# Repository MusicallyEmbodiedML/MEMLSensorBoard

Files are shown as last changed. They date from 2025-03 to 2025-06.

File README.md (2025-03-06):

# MEMLSensorBoard

Host board for up to 8 resistive sensors, with adjustable scale and offset.  Send to another board using serial or i2c.  Visual feedback with TFT screen.

## Hardware

Also hosts a ELI2040c board https://github.com/Emute-Lab-Instruments/ELI2040

## Software 

Runs on RP2040

Need TFT eSPI extension, with RP2040 GC9A01 driver

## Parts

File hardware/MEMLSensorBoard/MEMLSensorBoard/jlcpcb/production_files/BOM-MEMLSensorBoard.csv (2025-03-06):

Comment | Designator | Footprint | LCSC
100n | C1,C13,C14,C15,C16,C17,C18,C19,C2,C20,C3 | C_0603_1608Metric | C14663
1N5819 | D1 | D_SOD-323 | C191023
taper 0R0 | R25,R26,R27,R28,R29,R30,R31,R32 | R_0603_1608Metric | C21189
2k | R10,R12,R14,R16,R2,R4,R6,R8 | R_0603_1608Metric | C22975
22uf | C4 | C_0805_2012Metric | C45783
MCP6004 | U2,U3 | TSSOP-14_4.4x5mm_P0.65mm | C50282
100p | C10,C11,C12,C5,C6,C7,C8,C9 | C_Rect_L7.0mm_W2.5mm_P5.00mm | C5359302
74HC4051 | U4 | TSSOP-16_4.4x5mm_P0.65mm | C5645
Screw_Terminal_01x02 | J2,J3,J4,J5,J6,J7,J8,J9 | CONN-TH_WJ126V-5.0-2P | C8404
100k | RV11 | TRIM_3306F-1-104
100k | RV5 | TRIM_3306F-1-104
5k DNP | R3 | R_Axial_DIN0207_L6.3mm_D2.5mm_P7.62mm_Horizontal
~ | U1 | Round TFT 240x240
100k | RV13 | TRIM_3306F-1-104
taper-dnp | R18 | R_0603_1608Metric
taper-dnp | R24 | R_0603_1608Metric
5k DNP | R7 | R_Axial_DIN0207_L6.3mm_D2.5mm_P7.62mm_Horizontal
100k | RV1 | TRIM_3306F-1-104
100k | RV12 | TRIM_3306F-1-104
ELI2040B 1 | J1 | PinSocket_1x35_P2.54mm_Vertical
100k | RV8 | TRIM_3306F-1-104
5k DNP | R13 | R_Axial_DIN0207_L6.3mm_D2.5mm_P7.62mm_Horizontal
taper-dnp | R19 | R_0603_1608Metric
5k DNP | R9 | R_Axial_DIN0207_L6.3mm_D2.5mm_P7.62mm_Horizontal
Conn_02x03_Counter_Clockwise | J10 | IDC-Header_2x04_P2.54mm_Vertical
100k | RV9 | TRIM_3306F-1-104
100k | RV7 | TRIM_3306F-1-104
100k | RV3 | TRIM_3306F-1-104
100k | RV6 | TRIM_3306F-1-104
5k DNP | R1 | R_Axial_DIN0207_L6.3mm_D2.5mm_P7.62mm_Horizontal
100k | RV10 | TRIM_3306F-1-104
100k | RV4 | TRIM_3306F-1-104
100k | RV16 | TRIM_3306F-1-104
taper-dnp | R20 | R_0603_1608Metric
100k | RV14 | TRIM_3306F-1-104
5k DNP | R11 | R_Axial_DIN0207_L6.3mm_D2.5mm_P7.62mm_Horizontal
Conn_01x04 | J12 | PinHeader_1x04_P2.54mm_Vertical
100k | RV15 | TRIM_3306F-1-104
taper-dnp | R21 | R_0603_1608Metric
5k DNP | R15 | R_Axial_DIN0207_L6.3mm_D2.5mm_P7.62mm_Horizontal
Conn_02x16_Counter_Clockwise | J11 | IDC-Header_2x08_P2.54mm_Vertical
5k DNP | R5 | R_Axial_DIN0207_L6.3mm_D2.5mm_P7.62mm_Horizontal
taper-dnp | R22 | R_0603_1608Metric
100k | RV2 | TRIM_3306F-1-104
taper-dnp | R17 | R_0603_1608Metric
taper-dnp | R23 | R_0603_1608Metric

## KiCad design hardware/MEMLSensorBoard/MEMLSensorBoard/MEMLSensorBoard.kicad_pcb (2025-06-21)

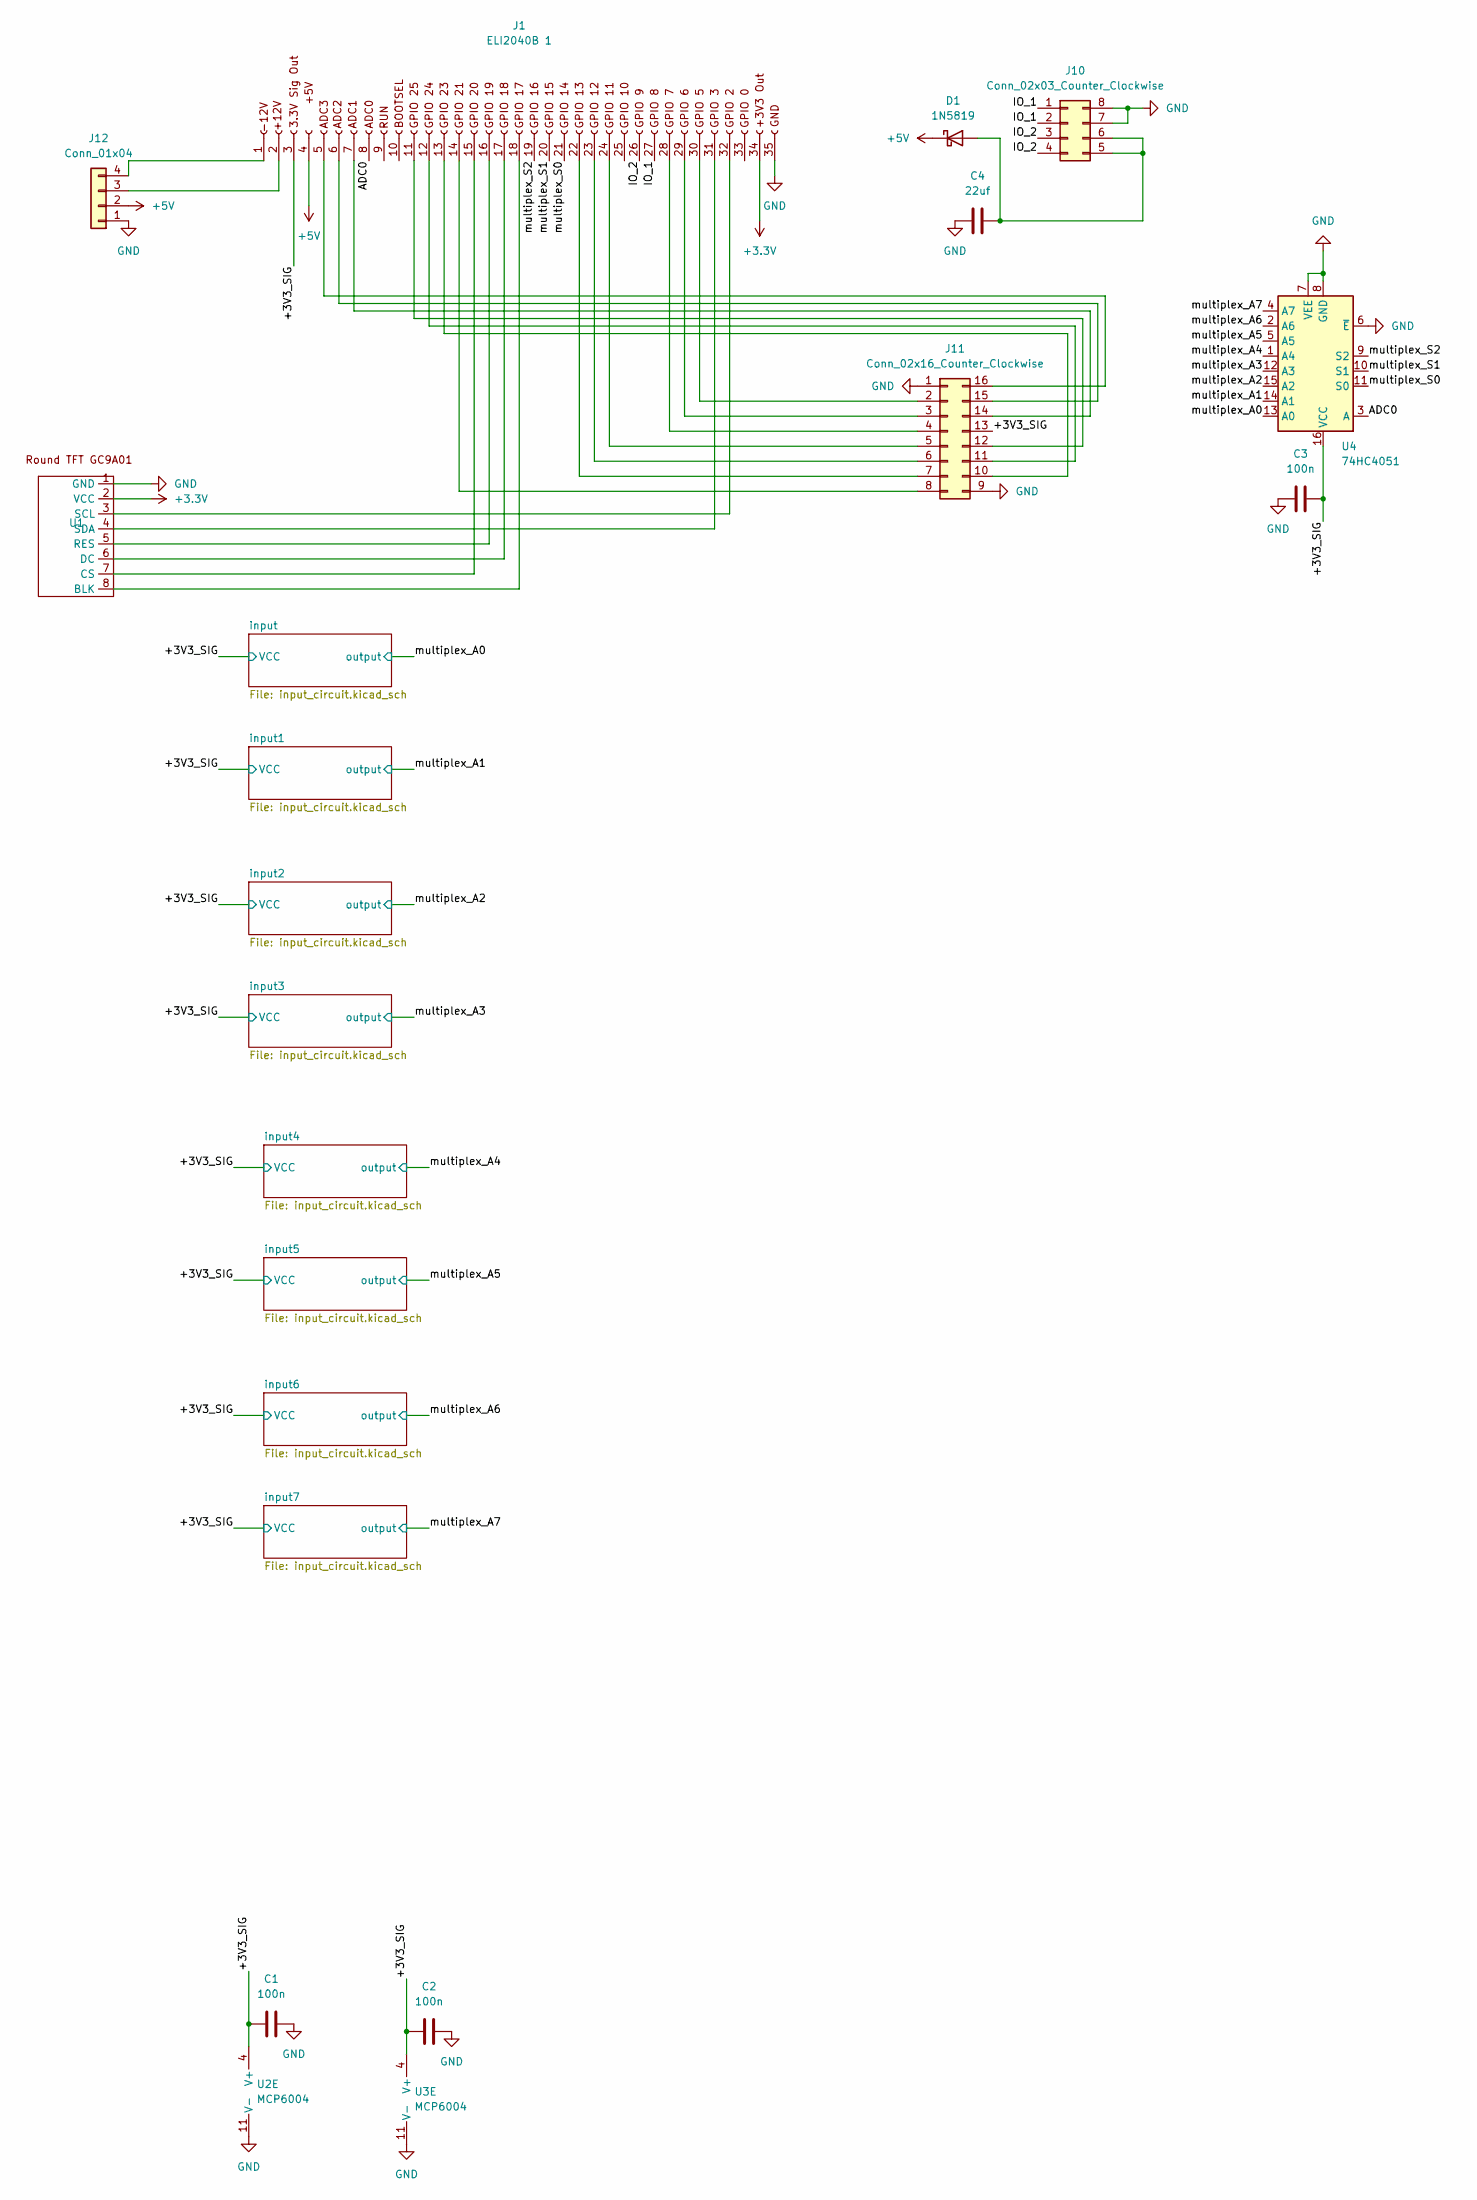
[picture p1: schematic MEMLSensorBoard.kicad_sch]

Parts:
C1, C2, C3: 100n; C_0603_1608Metric
C4: 22uf; C_0805_2012Metric
D1: 1N5819; D_SOD-323
J1: ELI2040B 1; PinSocket_1x35_P2.54mm_Vertical
J10: Conn_02x03_Counter_Clockwise; IDC-Header_2x04_P2.54mm_Vertical
J11: Conn_02x16_Counter_Clockwise; IDC-Header_2x08_P2.54mm_Vertical
J12: Conn_01x04; PinHeader_1x04_P2.54mm_Vertical
U1: Round TFT 240x240
U2, U3: MCP6004; TSSOP-14_4.4x5mm_P0.65mm
U4: 74HC4051; TSSOP-16_4.4x5mm_P0.65mm

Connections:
+3.3V: J1.34, U1.2 (VCC)
+5V: D1.1 (K), J1.4, J12.2
/+3V3_SIG: C1.1, C2.1, C3.1, J1.3, J11.13, U2.4 (V+), U3.4 (V+), U4.16 (VCC); also elsewhere on the board
/ADC0: J1.8, U4.3 (A)
/IO_1: J1.27, J10.1, J10.2
/IO_2: J1.26, J10.3, J10.4
/multiplex_A0: U2.1, U4.13 (A0); also elsewhere on the board
/multiplex_A1: U2.7, U4.14 (A1); also elsewhere on the board
/multiplex_A2: U4.15 (A2); also elsewhere on the board
/multiplex_A3: U2.14, U4.12 (A3); also elsewhere on the board
/multiplex_A4: U3.1, U4.1 (A4); also elsewhere on the board
/multiplex_A5: U3.7, U4.5 (A5); also elsewhere on the board
/multiplex_A6: U4.2 (A6); also elsewhere on the board
/multiplex_A7: U3.14, U4.4 (A7); also elsewhere on the board
/multiplex_S0: J1.21, U4.11 (S0)
/multiplex_S1: J1.20, U4.10 (S1)
/multiplex_S2: J1.19, U4.9 (S2)
GND: C1.2, C2.2, C3.2, C4.1, J1.35, J10.7, J10.8, J11.1, J11.9, J12.1, U1.1 (GND), U2.11 (V-), U3.11 (V-), U4.6 (~E), U4.7 (VEE), U4.8 (GND); also elsewhere on the board
unnamed: C4.2, D1.2 (A), J10.5, J10.6
unnamed: J1.2 (+12V), J12.3
unnamed: J1.1 (-12V), J12.4
unnamed: J1.5, J11.16
unnamed: J1.6, J11.15
unnamed: J1.7, J11.14
unnamed: J1.11, J11.12
unnamed: J1.12, J11.11
unnamed: J1.13, J11.10
unnamed: J1.14, J11.8
unnamed: J1.15, U1.7 (CS)
unnamed: J1.16, U1.5 (RES)
unnamed: J1.17, U1.6 (DC)
unnamed: J1.18, U1.8 (BLK)
unnamed: J1.22, J11.7
unnamed: J1.23, J11.6
unnamed: J1.24, J11.5
unnamed: J1.28, J11.4
unnamed: J1.29, J11.3
unnamed: J1.30, J11.2
unnamed: J1.31, U1.4 (SDA)
unnamed: J1.32, U1.3 (SCL)
unnamed 56: U2.3 (+); also elsewhere on the board
unnamed 57: U2.2 (-); also elsewhere on the board
unnamed 58: U2.5 (+); also elsewhere on the board
unnamed 59: U2.6 (-); also elsewhere on the board
unnamed 62: U2.12 (+); also elsewhere on the board
unnamed 63: U2.13 (-); also elsewhere on the board
unnamed 64: U3.3 (+); also elsewhere on the board
unnamed 65: U3.2 (-); also elsewhere on the board
unnamed 66: U3.5 (+); also elsewhere on the board
unnamed 67: U3.6 (-); also elsewhere on the board
unnamed 70: U3.12 (+); also elsewhere on the board
unnamed 71: U3.13 (-); also elsewhere on the board

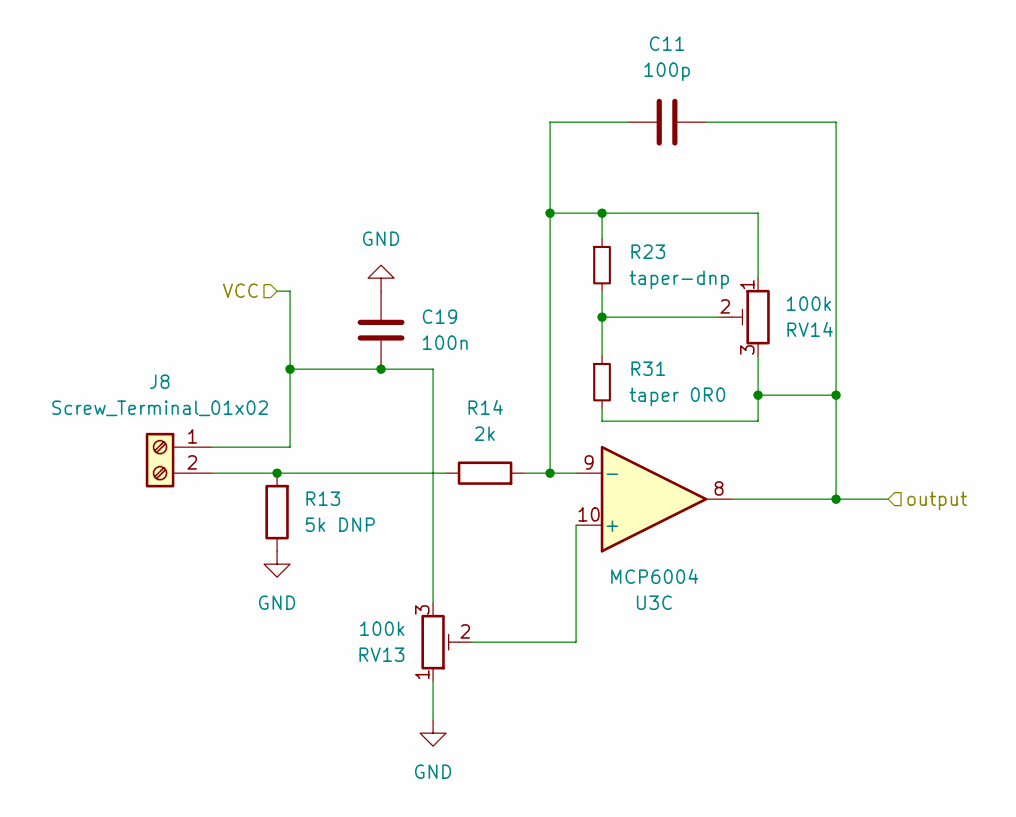
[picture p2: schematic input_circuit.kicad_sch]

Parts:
C11: 100p; C_Rect_L7.0mm_W2.5mm_P5.00mm; JLC C5359302
C19: 100n; C_0603_1608Metric
J8: Screw_Terminal_01x02; CONN-TH_WJ126V-5.0-2P; part WJ126V-5.0-2P; jlc C8404
R13: 5k DNP; R_Axial_DIN0207_L6.3mm_D2.5mm_P7.62mm_Horizontal
R14: 2k; R_0603_1608Metric
R23: taper-dnp; R_0603_1608Metric
R31: taper 0R0; R_0603_1608Metric; JLC C21189
RV13, RV14: 100k; TRIM_3306F-1-104
U3: MCP6004; TSSOP-14_4.4x5mm_P0.65mm

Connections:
/+3V3_SIG: C19.2, J8.1, RV13.3; also elsewhere on the board
/multiplex_A4: U3.1; also elsewhere on the board
/multiplex_A5: U3.7; also elsewhere on the board
/multiplex_A6: C11.2, R31.2, RV14.3, U3.8; also elsewhere on the board
/multiplex_A7: U3.14; also elsewhere on the board
GND: C19.1, R13.1, RV13.1; also elsewhere on the board
unnamed: J8.2, R13.2, R14.1
unnamed: R23.2, R31.1, RV14.2
unnamed 64: U3.3 (+); also elsewhere on the board
unnamed 65: U3.2 (-); also elsewhere on the board
unnamed 66: U3.5 (+); also elsewhere on the board
unnamed 67: U3.6 (-); also elsewhere on the board
unnamed: RV13.2, U3.10 (+)
unnamed: C11.1, R14.2, R23.1, RV14.1, U3.9 (-)
unnamed 70: U3.12 (+); also elsewhere on the board
unnamed 71: U3.13 (-); also elsewhere on the board

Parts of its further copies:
C5, C6, C7, C8, C9, C10, C12: 100p; C_Rect_L7.0mm_W2.5mm_P5.00mm; JLC C5359302
C13, C14, C15, C16, C17, C18, C20: 100n; C_0603_1608Metric
J2, J3, J4, J5, J6, J7, J9: Screw_Terminal_01x02; CONN-TH_WJ126V-5.0-2P; part WJ126V-5.0-2P; jlc C8404
R1, R3, R5, R7, R9, R11, R15: 5k DNP; R_Axial_DIN0207_L6.3mm_D2.5mm_P7.62mm_Horizontal
R2, R4, R6, R8, R10, R12, R16: 2k; R_0603_1608Metric
R17, R18, R19, R20, R21, R22, R24: taper-dnp; R_0603_1608Metric
R25, R26, R27, R28, R29, R30, R32: taper 0R0; R_0603_1608Metric; JLC C21189
RV1, RV2, RV3, RV4, RV5, RV6, RV7, RV8, RV9, RV10, RV11, RV12, RV15, RV16: 100k; TRIM_3306F-1-104

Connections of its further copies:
/+3V3_SIG: C13.2, C14.2, C15.2, C16.2, C17.2, C18.2, C20.2, J2.1, J3.1, J4.1, J5.1, J6.1, J7.1, J9.1, RV1.3, RV3.3, RV5.3, RV7.3, RV9.3, RV11.3, RV15.3; also elsewhere on the board
/multiplex_A0: C5.2, R25.2, RV2.3; also elsewhere on the board
/multiplex_A1: C6.2, R26.2, RV4.3; also elsewhere on the board
/multiplex_A2: C7.2, R27.2, RV6.3; also elsewhere on the board
/multiplex_A3: C8.2, R28.2, RV8.3; also elsewhere on the board
/multiplex_A4: C9.2, R29.2, RV10.3; also elsewhere on the board
/multiplex_A5: C10.2, R30.2, RV12.3; also elsewhere on the board
/multiplex_A7: C12.2, R32.2, RV16.3; also elsewhere on the board
GND: C13.1, C14.1, C15.1, C16.1, C17.1, C18.1, C20.1, R1.1, R3.1, R5.1, R7.1, R9.1, R11.1, R15.1, RV1.1, RV3.1, RV5.1, RV7.1, RV9.1, RV11.1, RV15.1; also elsewhere on the board
unnamed: J2.2, R1.2, R2.1
unnamed: J3.2, R3.2, R4.1
unnamed: J4.2, R5.2, R6.1
unnamed: J5.2, R7.2, R8.1
unnamed: J6.2, R9.2, R10.1
unnamed: J7.2, R11.2, R12.1
unnamed: J9.2, R15.2, R16.1
unnamed: R17.2, R25.1, RV2.2
unnamed: R18.2, R26.1, RV4.2
unnamed: R19.2, R27.1, RV6.2
unnamed: R20.2, R28.1, RV8.2
unnamed: R21.2, R29.1, RV10.2
unnamed: R22.2, R30.1, RV12.2
unnamed: R24.2, R32.1, RV16.2
unnamed 56: RV1.2; also elsewhere on the board
unnamed 57: C5.1, R2.2, R17.1, RV2.1; also elsewhere on the board
unnamed 58: RV3.2; also elsewhere on the board
unnamed 59: C6.1, R4.2, R18.1, RV4.1; also elsewhere on the board
unnamed 60: RV5.2; also elsewhere on the board
unnamed 61: C7.1, R6.2, R19.1, RV6.1; also elsewhere on the board
unnamed 62: RV7.2; also elsewhere on the board
unnamed 63: C8.1, R8.2, R20.1, RV8.1; also elsewhere on the board
unnamed 64: RV9.2; also elsewhere on the board
unnamed 65: C9.1, R10.2, R21.1, RV10.1; also elsewhere on the board
unnamed 66: RV11.2; also elsewhere on the board
unnamed 67: C10.1, R12.2, R22.1, RV12.1; also elsewhere on the board
unnamed 70: RV15.2; also elsewhere on the board
unnamed 71: C12.1, R16.2, R24.1, RV16.1; also elsewhere on the board

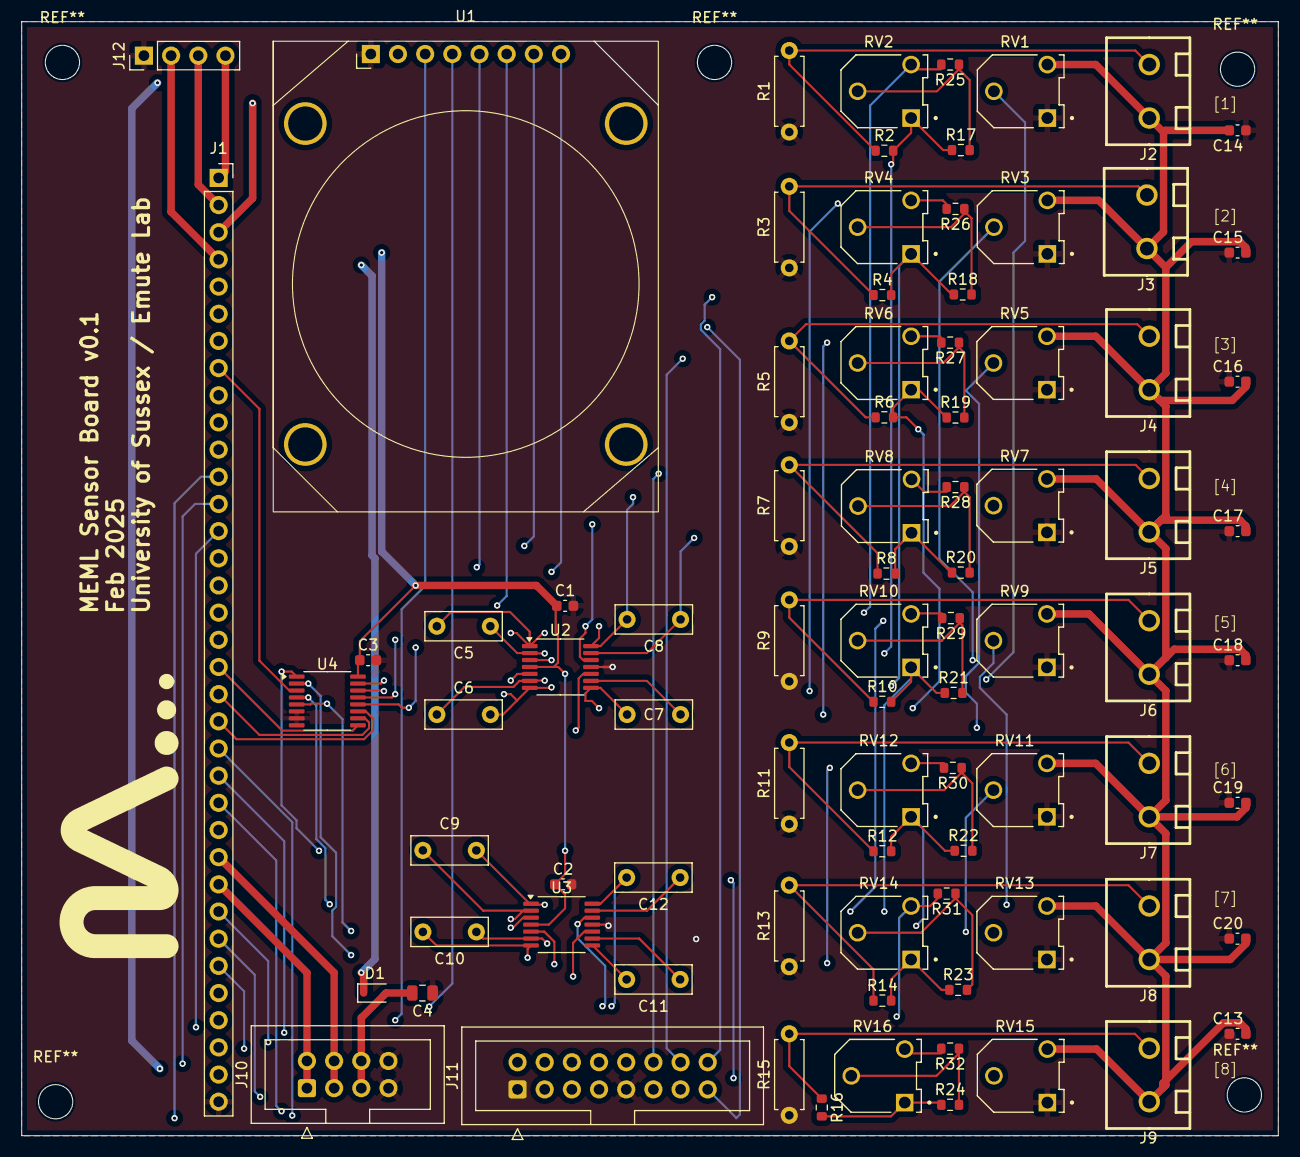
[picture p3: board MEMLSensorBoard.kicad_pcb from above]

Board: 4 copper layers, 117.5 x 104.1 mm, 85 parts (0 on the bottom side), 72 nets.

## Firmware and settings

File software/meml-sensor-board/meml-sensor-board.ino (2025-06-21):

#include <TFT_eSPI.h>
#include <array>
#include "pico/util/queue.h"
#include "SerialComms.hpp"

#define FAST_MEM __not_in_flash("data")

constexpr size_t MULTIPLEX_S0 = 14;
constexpr size_t MULTIPLEX_S1 = 15;
constexpr size_t MULTIPLEX_S2 = 16;


TFT_eSPI tft = TFT_eSPI();  // Invoke custom library
struct repeating_timer timerDisplay;

//sensors
std::array<size_t, 8> FAST_MEM sensorReadings, sensorReadingsCore1;
static queue_t FAST_MEM q_sensors;


inline bool __not_in_flash_func(displayUpdate)(__unused struct repeating_timer *t) {
  constexpr int barwidth = 16;
  constexpr int barheight=135;
  constexpr int barbase= 120 - (barheight/2.0);
  constexpr int barGap=18;
  constexpr int barcol = TFT_RED;
  constexpr int barcol2 = TFT_BLUE;
  constexpr int barLeft = 120 - (barGap*4);
  if (queue_try_remove(&q_sensors, sensorReadingsCore1.data())) {
    for(size_t i=0; i < 8; i++) {
      int thisBarHeight = barheight * (sensorReadingsCore1[i] / 4096.0);
      thisBarHeight = max(5, thisBarHeight);
      thisBarHeight = min(barheight, thisBarHeight);
      Serial.printf("%d %d %d\n", i, thisBarHeight, barheight - thisBarHeight);
      tft.fillRect(barLeft + (i * barGap), barbase, barwidth, barbase + thisBarHeight, barcol);
      tft.fillRect(barLeft + (i * barGap), barbase + thisBarHeight, barwidth, barheight - thisBarHeight, barcol2);
    }
  }
  return true;
}


void setup() {
  // put your setup code here, to run once:
  pinMode(22,1);
  pinMode(MULTIPLEX_S0, 1);
  pinMode(MULTIPLEX_S1, 1);
  pinMode(MULTIPLEX_S2, 1);
  digitalWrite(22,1);
  analogReadResolution(11);

  
  queue_init(&q_sensors, sizeof(float)*sensorReadings.size(), 1);

  for(auto &v: sensorReadings) {
    v=0;
  }
  Serial.begin();
  Serial2.setRX(9);
  Serial2.setTX(8);  
  Serial2.begin(115200);

  tft.begin();
  tft.setRotation(1);
  tft.setFreeFont(&FreeSans18pt7b);
  tft.fillScreen(TFT_GREEN);



}



void loop() {

  for(size_t sensorIdx=0; sensorIdx < 8; sensorIdx++) {
    
    //set the input using the multiplexer data lines
    digitalWrite(MULTIPLEX_S0, sensorIdx & 0b1);
    digitalWrite(MULTIPLEX_S1, (sensorIdx>>1) & 0b1);
    digitalWrite(MULTIPLEX_S2, (sensorIdx>>2) & 0b1);
    //;let the multiplexer settle
    delayMicroseconds(50);

    //make a reading
    auto ain = analogRead(26);
    sensorReadings[sensorIdx] = ain;
    queue_try_add(&q_sensors, sensorReadings.data());
    sendOverSerial(sensorIdx, ain / 2047.0);
    delay(1);
  }
  delay(30);
}

void setup1() {
  add_repeating_timer_ms(-39, displayUpdate, NULL, &timerDisplay);
}

void loop1() {
}
